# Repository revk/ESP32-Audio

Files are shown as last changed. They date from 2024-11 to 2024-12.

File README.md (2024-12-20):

## Amazon

This part if for Amazon - as this is the *manufacturers web site* and so used as proof of title and list price. It is also links to where you can buy.

|ASIN|List price|Title|
|-----|----|----|
|[B0DQH9SK8K](https://www.amazon.co.uk/dp/B0DQH9SK8K)|£35.00|Small ESP32-S3 high quality voice recorder board with stereo TDK ICS 43434 microphones, micro SD card slot, and charger circuit|

## Trademark

This is an open source project, but bear in mind you cannot sell boards bearing the Andrews & Arnold Ltd name, the A&A logo, the registered trademark AJK logo, or the GS1 allocated EANs assigned to Andrews & Arnold Ltd.

# Open†Mic

(† Open source)

This project provides software and PCB designs for working with I2S microphone and speaker, most notably a self contained battery operated audio recorder to micro SD card.

The software provides working for a number of different use cases.

The hardware is an audio recorder, but the [LED](https://github.com/revk/ESP32-LED) project also has audio hardware with microphones and speakers.

## Why use this?

There are loads of microphones and dictaphones at sensible prices, so why use this?

The main reason is flexibility - it is open source - the hardware can do a lot, and it already allows record to SD and upload by web post. It can eventually be a Bluetooth microphone, or a telephone or intercom, etc. You get to do what you like, and can make suggestions and pull requests and load your own code.

The other feature, which is becoming rarer these days, is that it is *stand alone*. No subscription. No accounts or sign up. No cloud services. Nobody training AI on your data.

## Button

Button works with short or long press (long is 3s).

* press to answer or end incoming SIP call
* press to start or stop recording
* hold (1s) to reject incoming SIP call
* hold (1s) to make a call
* hold (3s) to enter power off (will upload files at this point if option selected) - there is also an auto power off feature
* press to power back on

## Microphone

The software is designed to work with I2S audio input, and is coded and tested for two specific microphones. Others may work, but I2S has a number of options - so ask me if you need some other settings.

* [TDK T3902](https://www.lcsc.com/datasheet/lcsc_datasheet_2401291125_TDK-InvenSense-MMICT390200012_C3171752.pdf) is an I2S PDM microphone (so 16 bits per sample)
* [TDK ICS-43434](https://www.lcsc.com/datasheet/lcsc_datasheet_2312010321_TDK-InvenSense-ICS-43434_C5656610.pdf) is an I2S microphone (24 bits) with sample rates up to 51.6kHz

The software can work with one or two microphones (i.e. mono or stereo). When two microphones, they are the same type, on the same bus, with one wired as *left* and one as *right* channel. 

## Speaker

For I2S output the [MAX98357A](https://www.lcsc.com/datasheet/lcsc_datasheet_2106070436_Analog-Devices-Inc--Maxim-Integrated-MAX98357AEWL-T_C2682619.pdf) is recommended. This can be one chip working as *left*, *right*, or *left+right* channels, or as two chips on the same bus, one as *left* and one as *right*.

* `spkrate` sets the speaker rate, which (for the MAX98357A) can be 8kHz, 16kHz, 32kHz, 44.1kHz, 48kHz, 88.2kHz, or 96kHz.

## Input processing

The input from the I2S microphones can be mono or stereo, and can be 16 or 24 bits. If a PDM microphone is used it is always 16 bits. If the ICS-43434 microphone is used it is received as 24 bits which can either be passed on unprocessed, or converted to 16 bits.

* `micws` is the GPIO for the channel, if not set it is assumed to be PDM mode
* `micrate` sets the sample rate
* `micstereo` is set for stereo working
* `micright` is set for *right* channel when mono.
* `micgain` sets the gain for processing 24 bits to 16

When `micgain` is set to `0`, or when using a PDM microphone, the samples (stereo or mono) are used as received, with no processing. This means for PDM mode this is 16 bits per sample, and for ICS-43434 it is 24 bits per sample.

When `micgain` is not `0`, for ICS-43434, the 24 bit samples are processed by multiplying by `micgain/256` and clipping to 16 bits (`-32768` to `32767`). A `micgain` of `8` works well for speech.

## Output

The output via the speaker can be one of the following - normally managed via MQTT control messages or web interface, though SIP is automatic when a call arrives.

* Morse code (including prosigns in `[]`, e.g. `[INT]`) and punctuation
* DTMF
* Playing a WAV file from SD card (TODO)
* SIP (see below)

The format will depend on the source - the MAX98357A can handle 16, 24, or 32 bits per channel.

## Audio recorder



The main use of this software is as an *audio recorder*. This will record from the microphone(s) to a WAV file on the micro SD card. It allows a `button` GPIO to start/stop recording and power on/off. It allows for a separate WS2812 record status LED. The PCB design includes LiPo charging.

Options are planned:-

* Stream audio over WiFI by some means
* Stream audio over bluetooth, if ever I work out how to do that

An option exists to upload files to a web page as a `POST`, renaming the file slightly once uploaded so not uploaded twice. This is done when you hold the button to *power off`*.

An option exists to delete old files if space needed for new file.

## SIP working

The software allows settings `siphost`, `sipuser`, and `sippass`, such that the device registers with a SIP server.

Once registered it can then accept a call, and pass audio both ways over RTP, 8kHz alaw. Only one call at a time.

* The microphone is changed to mono (channel selected by `micright`) 8kHz, and either 16 bit PDM, or processed 24 bit to 16 bit using `micgain`, and then companded to alaw.
* The speaker is sent dual mono audio expanded from 8kHz alaw to 16 bits per sample.

Note that there is no echo cancellation, so a caller is likely to hear their own audio come back to them.

Once the call is complete, the audio processing reverts to previous settings.

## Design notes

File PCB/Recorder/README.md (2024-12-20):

# Audio recorder board

The Audio record board provides a shirt mount Audio board.

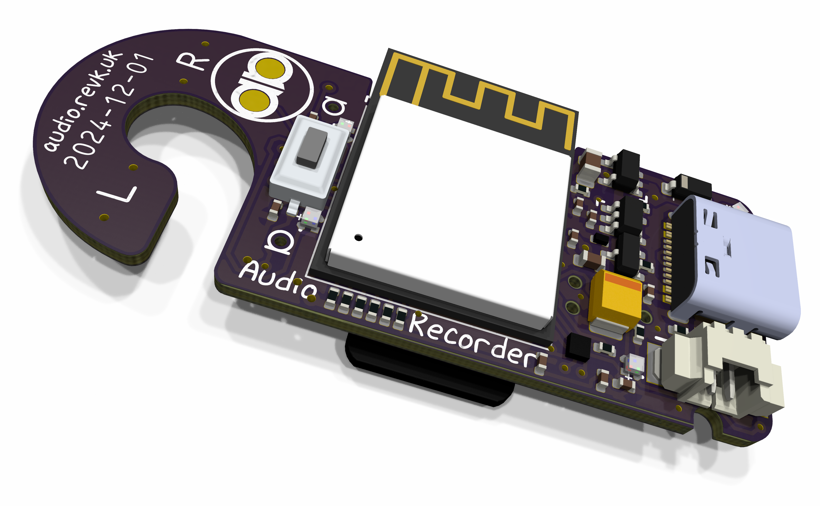
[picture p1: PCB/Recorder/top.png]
Top

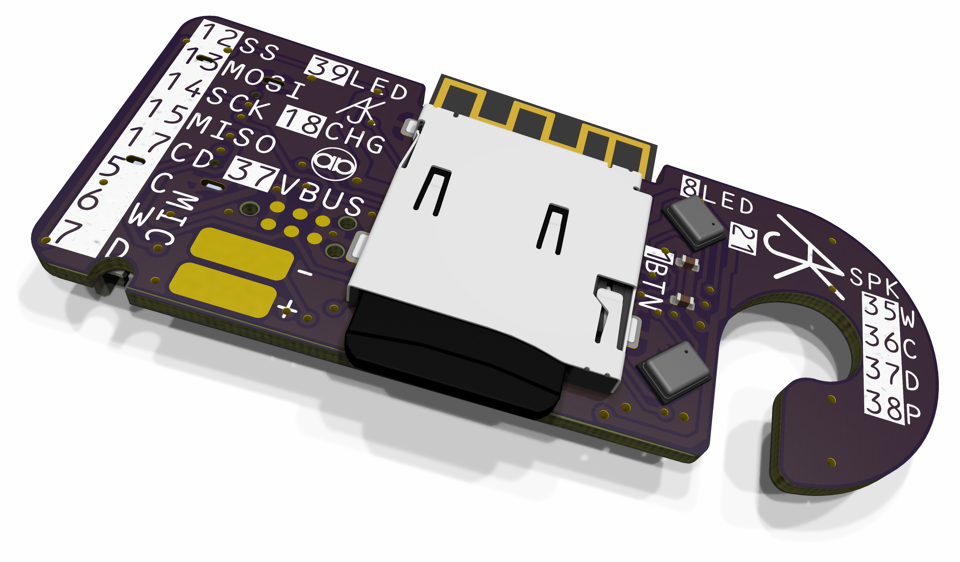
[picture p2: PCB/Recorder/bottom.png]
Bottom


Features

* LiPo battery handling and charging
* Mic, stereo TDK ICS 43434 24 bit
* SD card slot
* Button to start/stop recording, etc.

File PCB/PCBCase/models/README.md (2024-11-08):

# Models

The `models` directory contains models for the parts. These are OpenSCAD code to draw the part. This does not have to be pretty, and will often be a simple cuboid. It is used to create a cavity in the case, and any necessary holes, etc.

## Filename

For each part a file name is found for the necessary OpenSCAD code. This is done by checking a number of possible filenames until one if found.

- If there is an `LCSC Part #`, then this is checked. e.g. `C265103`
- The footprint is checked exactly, without prefix, e.g. `RevK:JST_EH_S5B-EH_1x05_P2.50mm_Horizontal` will check for `JST_EH_S5B-EH_1x05_P2.50mm_Horizontal`
- If neither of those matched, then the name of each 3D model is processed (all of them, not just the first) isong the filename without directory or suffix, e.g. `${KICAD6_3DMODEL_DIR}/Connector_JST.3dshapes/JST_EH_S5B-EH_1x05_P2.50mm_Horizontal.wrl` would check `JST_EH_S5B-EH_1x05_P2.50mm_Horizontal`.

In any case, when checking a filename (apart from the LCSC Part), any numbers in the filename are replaced with `ℕ`, e.g. for `JST_EH_S5B-EH_1x05_P2.50mm_Horizontal` the filenames checked are as follows, matching the first one found.

- `JST_EH_SℕB-EH_1x05_P2.50mm_Horizontal`
- `JST_EH_S5B-EH_ℕx05_P2.50mm_Horizontal`
- `JST_EH_S5B-EH_1xℕ_P2.50mm_Horizontal`
- `JST_EH_S5B-EH_1x05_Pℕmm_Horizontal`
- `JST_EH_S5B-EH_1x05_P2.50mm_Horizontal`

## How OpenSCAD is called

- If `N` was used in the filename, then `N` is set to the numeric value, e.g. ``JST_EH_S5B-EH_1xN_P2.50mm_Horizontal.wrl`` will have `N` et to `5`.
- For the part shape itself, `part` is set `true`.
- For the associated holes, `hole` is set `true`.
- For the associated block, `block` is set `true`.

This basically means the OpenSCAD can be called for three things...

In all cases the origin is the base of the centre of the part. The orientation is as per the 3D model.

### Orientation

When using the part number or footprint the orientation of the part matters, but when using the 3D model the exact 3D model orientation matters, so offset and rotations for the 3D model matter.

### Part

The `part` simply needs to cover the physical size/shape of the part. A function `module b(cx,cy,z,w,l,h)` is provided allowing a simple cuboid. It is possible for the part to go below the z axis, e.g. for the leads for through hole parts.

### Hole

The `hole` covers any holes in the case. This can be holes through the top of the case, e.g. for an LED to be visible. It can also cover holds in the side of the case for plugs that go in to a connector, etc.

When a hole goes through the side, the case itself is adjusted to have the cut line through the hole.

In either case, holes should be big enough for any sensible size of case.

Obviously only some parts need a hole.

### Block

The `block` is rarely used. It provides for a part of the case that must be present. It is added after the cavity is create, but before any holes. One use cases are a channel/tube around a hole for an LED in the top of the case, but this has to allow clear space on the PCB for the channel as adjacent parts won't cut in to the channel. Another use case is something like a tamper switch where a part of the case has to be present to press on the switch.

The block has to be big enough for any sensible size of case, it is truncated so it is within the case.

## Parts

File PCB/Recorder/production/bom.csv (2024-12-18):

Designator | Footprint | Quantity | Value | LCSC Part #
C1 | CP_EIA-3528-21_Kemet-B | 1 | 220uF Tant | C122649
C10, C13, C2, C4, C5, C6, C8 | C_0402 | 7 | 100nF
C11, C7 | C_0402 | 2 | 10uF 6.3V | C15525
C16 | C_0805 | 1 | 100uF | C141660
C3 | C_0603 | 1 | 22uF
C9 | C_0402 | 1 | 1uF
D1, D4, D5, D6 | SMD1010 | 4 | XL-1010RGBC-WS2812B | C5349953
D2 | DFN1006-2L | 1 | ~ | C5137770
D3 | D_SOD-123 | 1 | MBR0530
J1 | 1.25T-2PWT (Molex 532610271) | 1 | Battery | C177225
J4 | TF_PUSH | 1 | TF_PUSH | C393941
J5 | USB-C-Socket-H | 1 | USB-C-Socket-H | C709357
Q2 | SOT-23 | 1 | CJ2301 | C8547
R1, R10, R11, R12, R13, R14, R2, R3, R7, R8, R9 | R_0402 | 11 | 10K
R5, R6 | R_0402 | 2 | 5K1
SW1 | TS-1092S-B3D2-G | 1 | SW_Push
U1 | ICS43434_MEMS_Mic_Open | 1 | R | C5656610
U2 | ICS43434_MEMS_Mic_Open | 1 | L | C5656610
U3 | SOT-23-5 | 1 | TP4054 | C668215
U4 | SOT-23-5 | 1 | ME6211C33M5G-N | C82942
U6 | ESP32-S3-MINI-1 | 1 | ESP32-S3-MINI-1 | C3013941

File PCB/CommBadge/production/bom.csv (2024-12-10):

Designator | Footprint | Quantity | Value | LCSC Part #
C1 | CP_EIA-3528-21_Kemet-B | 1 | 220uF Tant | C122649
C10, C11, C12, C14, C15, C16, C17, C18, C2, C6 | C_0402 | 10 | 100nF
C13, C7, C8 | C_0402 | 3 | 10uF | C15525
C3 | C_0603 | 1 | 22uF
C4 | C_0805 | 1 | 100uF | C141660
C5 | C_0603 | 1 | 10uF 35V | C194427
C9 | C_0402 | 1 | 1uF
D1, D3 | DFN1006-2L | 2 | ~ | C5137770
D2 | D_SOD-123 | 1 | MBR0530
D4, D5, D6, D7, D8, D9 | SMD1010 | 6 | XL-1010RGBC-WS2812B | C5349953
J2 | 1.25T-2PWT (Molex 532610271) | 1 | Battery | C177225
J5 | USB-C-Socket-H | 1 | USB-C-Socket-H | C709357
LS1 | KLJ-Speaker | 1 | Speaker | C18186315
Q1 | SOT-23 | 1 | CJ2301 | C5224170
R1, R2, R3, R4 | R_0402 | 4 | 10K
R5, R6 | R_0402 | 2 | 5K1
R8 | R_0402 | 1 | 634K
SW2 | TS-1092S-B3D2-G | 1 | SW_Push
U2 | WLP-1.437mmx1.347mm-0.21mm-ball | 1 | MAX98357A
U3 | SOT-23-5 | 1 | TP4054 | C668215
U4 | SOT-23-5 | 1 | ME6211C33M5G-N | C82942
U5 | ICS43434_MEMS_Mic_Open | 1 | L | C5656610
U6 | ESP32-S3-MINI-1 | 1 | ESP32-S3-MINI-1 | C3013941
U7 | ICS43434_MEMS_Mic_Open | 1 | R | C5656610

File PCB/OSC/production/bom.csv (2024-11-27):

Designator | Footprint | Quantity | Value | LCSC Part #
C1 | CP_EIA-3528-21_Kemet-B | 1 | 220uF Tant | C122649
C10 | C_0603_ | 1 | 10uF 35V | C194427
C11 | C_0603_ | 1 | 10uF 6.3V | C1691
C12 | C_0603_ | 1 | 100nF
C15, C2 | C_0402 | 2 | 100nF
C3 | C_0603 | 1 | 22uF
C5 | C_0603 | 1 | 10uF 35V | C194427
C7, C8 | C_0402 | 2 | 10uF | C15525
C9 | C_0402 | 1 | 1uF
D1 | SMD1010 | 1 | XL-1010RGBC-WS2812B | C5349953
D2, D3, D4, D5 | DFN1006-2L | 4 | ~ | C5137770
J2 | WAGO-2060-453-998-404 | 1 | Wago | C2765056
J4 | WAGO-2060-452-998-404 | 1 | DC | C2765055
J5 | USB-C-Socket-H | 1 | USB-C-Socket-H | C709357
J6 | WAGO-2060-452-998-404 | 1 | RELAY1 | C2765055
J7 | WAGO-2060-452-998-404 | 1 | RELAY2 | C2765055
L2 | L_4x4_ | 1 | 10uH
R1 | R_0402 | 1 | 124K
R10, R7 | R_0402 | 2 | 1K
R14 | R_0402_ | 1 | 39k2
R15 | R_0402_ | 1 | 1M
R2, R3 | R_0402 | 2 | 10K
R4 | R_0402_ | 1 | 124k
R5, R6 | R_0402 | 2 | 5K1
SW1, SW3 | TS-1092S-B3D2-G | 2 | SW_Push
SW2 | Reed-59170 | 1 | SW_Reed | C315909
U1 | ICS43434_MEMS_Mic | 1 | ICS43434_MEMS_Mic | C5656610
U3, U8 | SO-4_4.4x4.3mm_P2.54mm | 2 | Relay | C2691608
U4 | SOT-23 | 1 | 78L05 | C22392284
U6 | ESP32-S3-MINI-1 | 1 | ESP32-S3-MINI-1 | C3013941
U7 | SOT-23-6-MD8942 | 1 | MD8942 | C2684786
U9 | VEML6040 | 1 | VEML6040 | C78465

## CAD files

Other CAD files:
PCB/PCBCase/models/Crystal_SMD_Abracon_ABM8G-4Pin_3.2x2.5mm.scad
PCB/PCBCase/models/PinHeader_1x0_P1.27mm_Vertical.scad
PCB/PCBCase/models/PinHeader_1x0_P2.54mm_Horizontal.scad
PCB/PCBCase/models/PinHeader_1x0_P2.54mm_Vertical.scad
PCB/PCBCase/case.scad
PCB/PCBCase/models/22057025.scad
PCB/PCBCase/models/22057035.scad
PCB/PCBCase/models/22057045.scad
PCB/PCBCase/models/22057055.scad
PCB/PCBCase/models/22057065.scad
PCB/PCBCase/models/22057075.scad
PCB/PCBCase/models/22057085.scad
PCB/PCBCase/models/22057095.scad
PCB/PCBCase/models/22057105.scad
PCB/PCBCase/models/653612.scad
PCB/PCBCase/models/D_0603_1608Metric.scad
PCB/PCBCase/models/D_0805_2012Metric.scad
PCB/PCBCase/models/D_1206_3216Metric.scad
PCB/PCBCase/models/ESE58L61B.scad
PCB/PCBCase/models/ESP32-WROOM-32.scad
PCB/PCBCase/models/HSOP-8-1EP_3.9x4.9mm_P1.27mm_EP2.41x3.1mm.scad
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

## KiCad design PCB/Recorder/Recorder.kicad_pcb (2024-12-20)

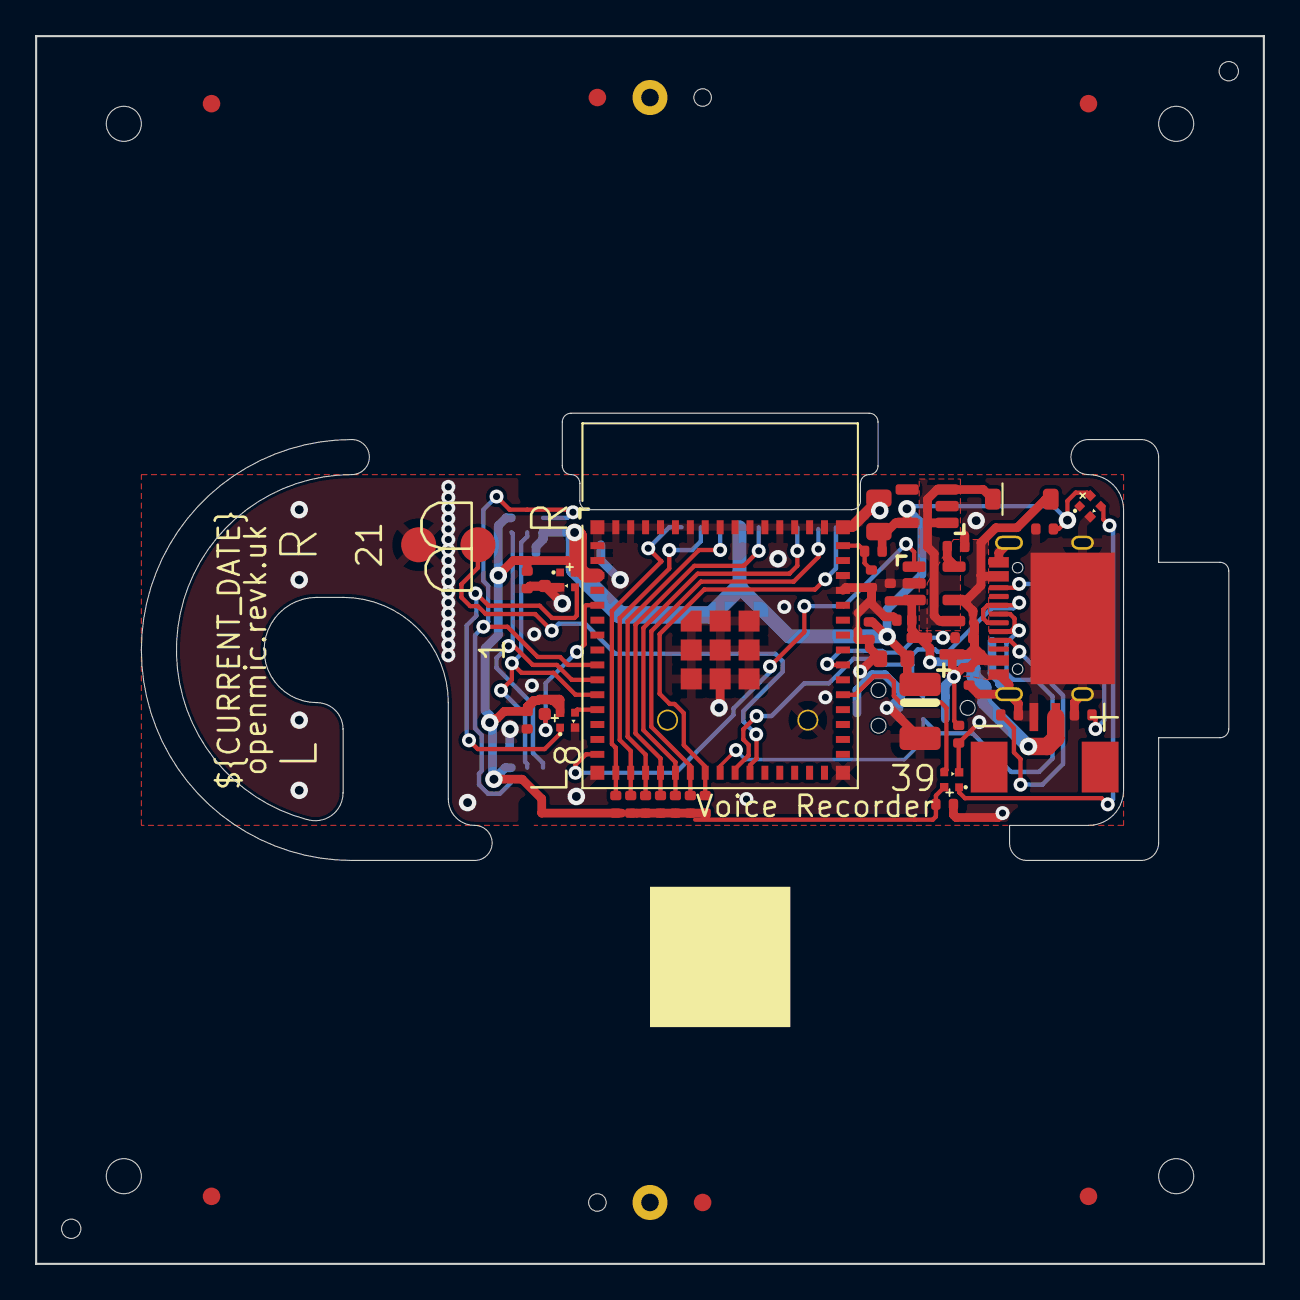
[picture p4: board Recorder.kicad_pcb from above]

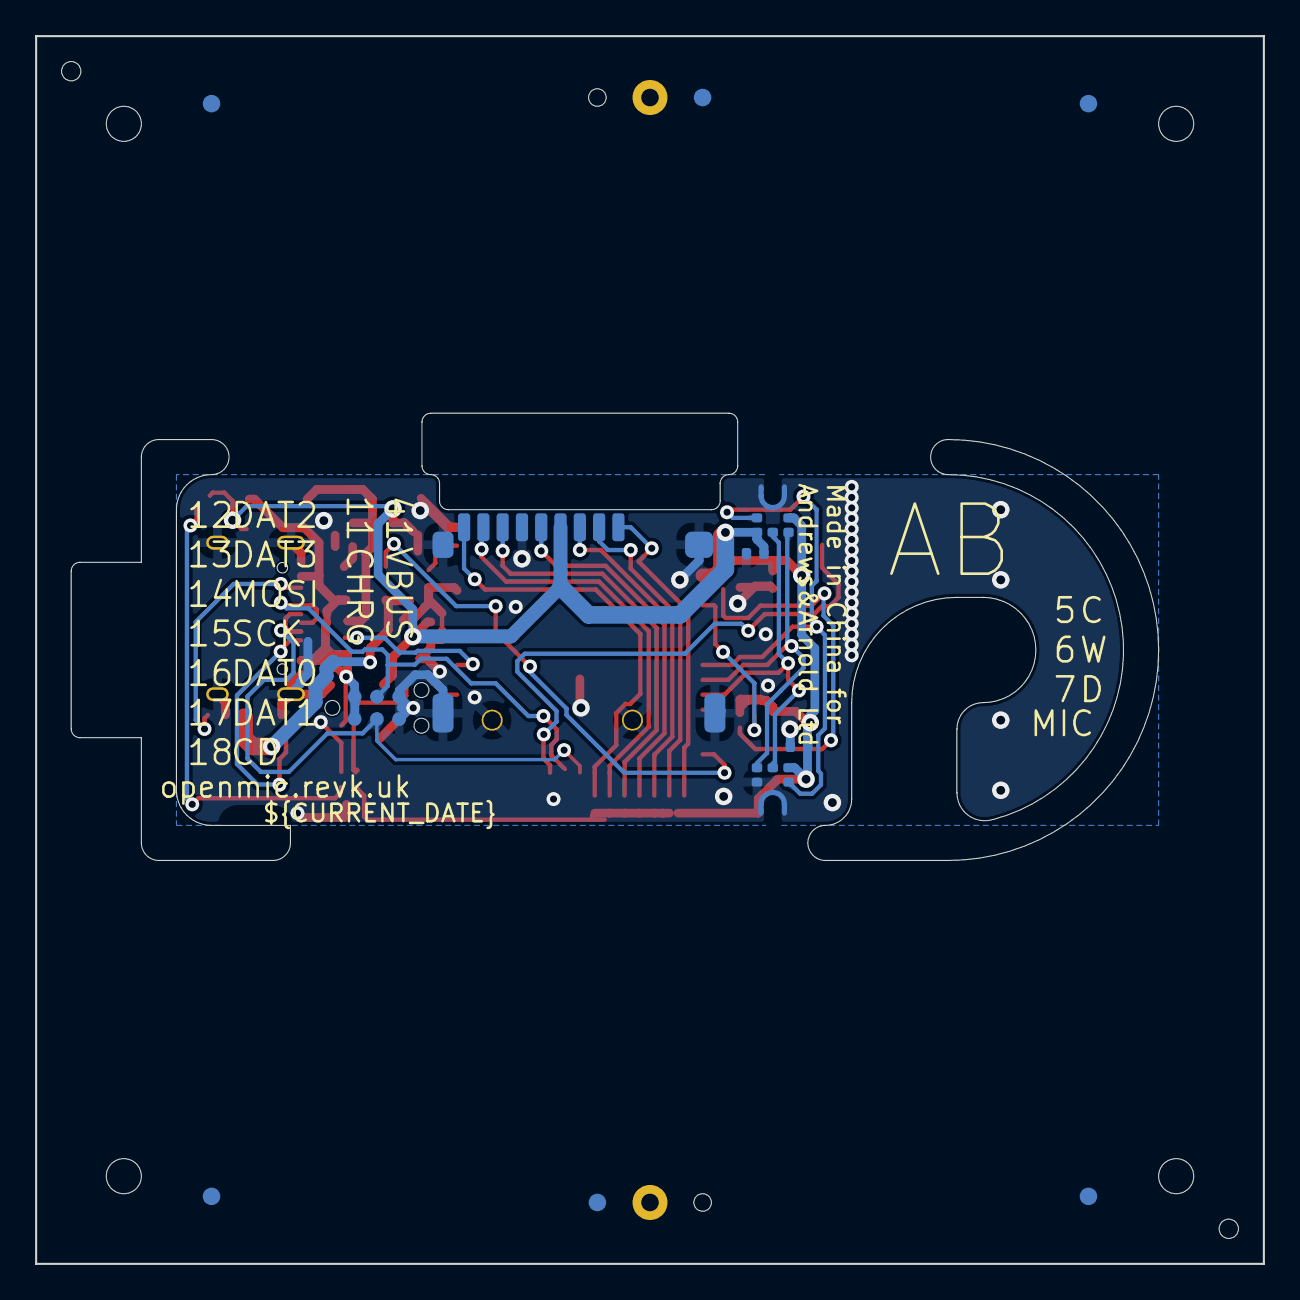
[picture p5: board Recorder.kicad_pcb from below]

Board: 2 copper layers, 70.0 x 70.0 mm, 47 parts (7 on the bottom side), 29 nets.

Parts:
C1: 220uF Tant; CP_EIA-3528-21_Kemet-B
C2, C4, C5, C6, C8, C10, C13: 100nF; C_0402
C3: 22uF; C_0603
C7, C11: 10uF 6.3V; C_0402
C9: 1uF; C_0402
C16: 100uF; C_0805
D1, D4, D5, D6: XL-1010RGBC-WS2812B; SMD1010
D2: DFN1006-2L
D3: MBR0530; D_SOD-123
J1: Battery; 1.25T-2PWT (Molex 532610271)
J2: Reset; AA-Pad
J3: TC2030-USB-NL-DS; Tag-Connect_TC2030-IDC-NL_2x03_P1.27mm_Vertical
J4: TF_PUSH
J5: USB-C-Socket-H
PCB1: 70x70; PCB7070
Q2: CJ2301; SOT-23
R1, R2, R3, R7, R8, R9, R10, R11, R12, R13, R14: 10K; R_0402
R5, R6: 5K1; R_0402
SW1: SW_Push; TS-1092S-B3D2-G
U1: R; ICS43434_MEMS_Mic_Open
U2: L; ICS43434_MEMS_Mic_Open
U3: TP4054; SOT-23-5
U4: ME6211C33M5G-N; SOT-23-5
U6: ESP32-S3-MINI-1
V1, V2: VCUT70N

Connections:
+3V3: C1.1, C2.1, C3.1, C4.1, C5.1, C6.1, C8.2, C10.1, C13.2, C16.1, D1.2 (+), D4.2 (+), D5.2 (+), D6.2 (+), J4.4 (VDD), R2.1, R3.1, R9.1, R10.1, R11.1, R12.1, R13.1, R14.1, U1.2 (LR), U1.5 (VDD), U2.5 (VDD), U4.5 (OUT), U6.3 (3V3)
BLINK: D1.4 (I), U6.35 (GPIO39)
BUTTON: SW1.2, U6.5 (GPIO1)
CHARGING: U3.1 (STAT), U6.15 (GPIO11)
D+: J3.4 (D+), J5.A6 (D+), J5.B6 (D+), U6.24 (GPIO20)
D-: J3.3 (D-), J5.A7 (D-), J5.B7 (D-), U6.23 (GPIO19)
GND: C1.2, C2.2, C3.2, C4.2, C5.2, C6.2, C7.2, C8.1, C9.2, C10.2, C11.2, C13.1, C16.2, D1.3 (-), D2.1, D4.3 (-), D5.3 (-), D6.3 (-), J1.2, J2.1, J3.5 (GND), J3.6 (GND), J4.6 (VSS), J4.S (SHIELD), J5.A1 (GND), J5.A12 (GND), J5.B1 (GND), J5.B12 (GND), J5.S1 (SHIELD), R1.1, R5.2, R6.1, R8.2, SW1.1, U1.3 (GND), U2.2 (LR), U2.3 (GND), U3.2 (VSS), U4.2 (GND), U6.1 (GND), U6.2 (GND), U6.42 (GND), U6.43 (GND), U6.46 (GND), U6.47 (GND), U6.48 (GND), U6.49 (GND), U6.50 (GND), U6.51 (GND), U6.52 (GND), U6.53 (GND), U6.54 (GND), U6.55 (GND), U6.56 (GND), U6.57 (GND), U6.58 (GND), U6.59 (GND), U6.60 (GND), U6.61 (GND), U6.62 (GND), U6.63 (GND), U6.64 (GND), U6.65 (GND)
LEDMIC: D5.4 (I), U6.12 (GPIO8)
unnamed: D1.1 (O), D6.4 (I)
unnamed: D3.1 (K), Q2.2 (S), U4.1 (IN), U4.3 (EN)
unnamed: D4.4 (I), D5.1 (O)
unnamed: J2.2, U6.25 (GPIO21)
unnamed: J5.A5 (CC1), R5.1
unnamed: J5.B5 (CC2), R6.2
unnamed: R1.2, U3.5 (PROG)
unnamed: C9.1, R2.2, U6.45 (EN)
unnamed: R7.1, U6.37 (GPIO41)
SCK: U1.4 (SCK), U2.4 (SCK), U6.9 (GPIO5)
SD: U1.6 (SD), U2.6 (SD), U6.11 (GPIO7)
SDCD: J4.9 (CD), R3.2, U6.22 (GPIO18)
SDCLK: J4.5 (CLK), R11.2, U6.19 (GPIO15)
SDCMD: J4.3 (CMD), R12.2, U6.18 (GPIO14)
SDDAT0: J4.7 (DAT0), R10.2, U6.20 (GPIO16)
SDDAT1: J4.8 (DAT1), R9.2, U6.21 (GPIO17)
SDDAT2: J4.1 (DAT2), R14.2, U6.16 (GPIO12)
SDDAT3: J4.2 (DAT3/CD), R13.2, U6.17 (GPIO13)
VBAT: C7.1, D2.2, J1.1, Q2.3 (D), U3.3 (VBAT)
VBUS: C11.1, D3.2 (A), J3.1 (VBUS), J3.2 (VBUS), J5.A4 (VBUS), J5.A9 (VBUS), J5.B4 (VBUS), J5.B9 (VBUS), Q2.1 (G), R7.2, R8.1, U3.4 (VDD)
WS: U1.1 (WS), U2.1 (WS), U6.10 (GPIO6)

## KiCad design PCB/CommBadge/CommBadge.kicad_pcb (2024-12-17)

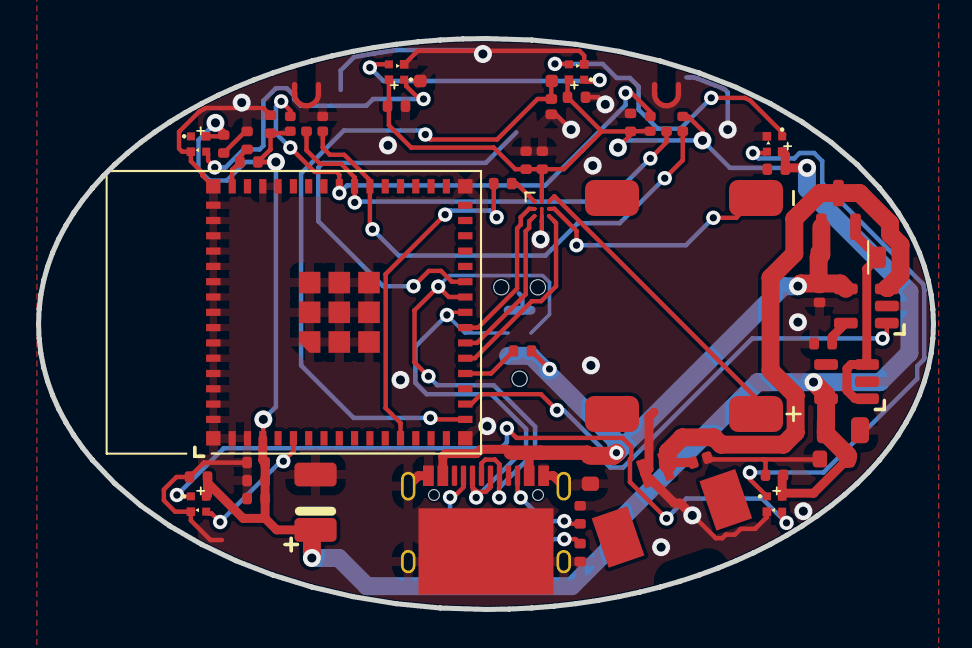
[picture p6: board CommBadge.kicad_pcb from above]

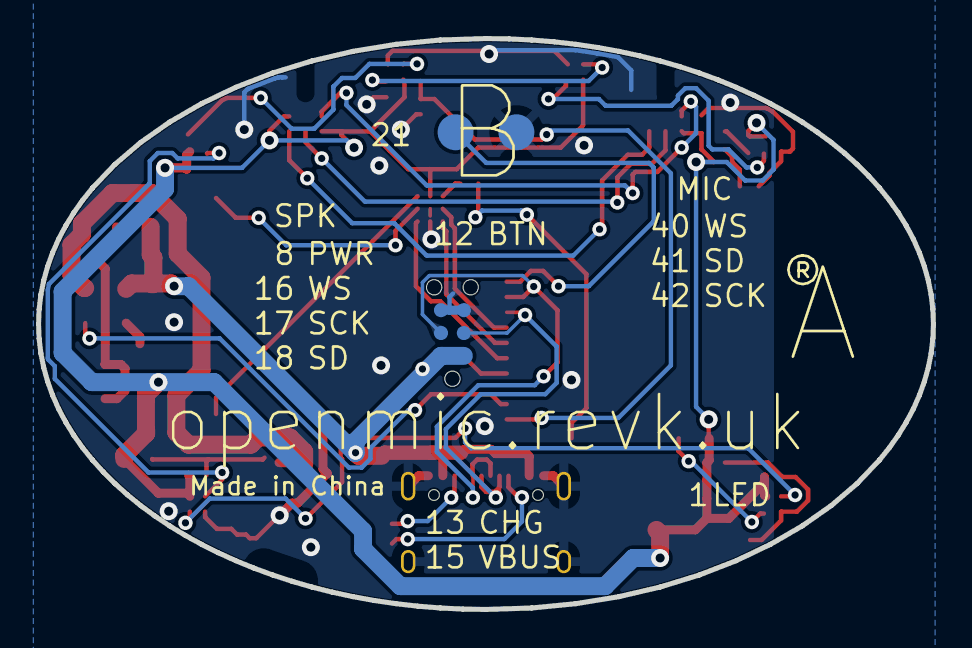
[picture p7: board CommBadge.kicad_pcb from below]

Board: 2 copper layers, 49.7 x 31.7 mm, 47 parts (2 on the bottom side), 31 nets.

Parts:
C1: 220uF Tant; CP_EIA-3528-21_Kemet-B
C2, C6, C10, C11, C12, C14, C15, C16, C17, C18: 100nF; C_0402
C3: 22uF; C_0603
C4: 100uF; C_0805
C5: 10uF 35V; C_0603
C7, C8, C13: 10uF; C_0402
C9: 1uF; C_0402
D1, D3: DFN1006-2L
D2: MBR0530; D_SOD-123
D4, D5, D6, D7, D8, D9: XL-1010RGBC-WS2812B; SMD1010
J1: Reset; AA-Pad
J2: Battery; 1.25T-2PWT (Molex 532610271)
J3: TC2030-USB-NL-DS; Tag-Connect_TC2030-IDC-NL_2x03_P1.27mm_Vertical
J5: USB-C-Socket-H
LS1: Speaker; KLJ-Speaker
Q1: CJ2301; SOT-23
R1, R2, R3, R4: 10K; R_0402
R5, R6: 5K1; R_0402
R8: 634K; R_0402
SW2: SW_Push; TS-1092S-B3D2-G
U2: MAX98357A; WLP-1.437mmx1.347mm-0.21mm-ball
U3: TP4054; SOT-23-5
U4: ME6211C33M5G-N; SOT-23-5
U5: L; ICS43434_MEMS_Mic_Open
U6: ESP32-S3-MINI-1
U7: R; ICS43434_MEMS_Mic_Open

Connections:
+3V3: C1.1, C2.1, C3.1, C4.1, C6.2, C7.1, C8.1, C10.2, C11.1, C12.1, C13.1, C14.1, C15.1, C16.1, C17.1, C18.1, D4.2 (+), D5.2 (+), D6.2 (+), D7.2 (+), D8.2 (+), D9.2 (+), R2.1, U2.A2 (VDD), U4.5 (OUT), U5.5 (VDD), U6.3 (3V3), U7.2 (LR), U7.5 (VDD)
CHARGING: U3.1 (STAT), U6.17 (GPIO13)
D+: J3.4 (D+), J5.A6 (D+), J5.B6 (D+), U6.24 (GPIO20)
D-: J3.3 (D-), J5.A7 (D-), J5.B7 (D-), U6.23 (GPIO19)
GND: C1.2, C2.2, C3.2, C4.2, C5.2, C6.1, C7.2, C8.2, C9.2, C10.1, C11.2, C12.2, C13.2, C14.2, C15.2, C16.2, C17.2, C18.2, D1.1, D3.1, D4.3 (-), D5.3 (-), D6.3 (-), D7.3 (-), D8.3 (-), D9.3 (-), J1.1, J2.2, J3.5 (GND), J3.6 (GND), J5.A1 (GND), J5.A12 (GND), J5.B1 (GND), J5.B12 (GND), J5.S1 (SHIELD), R1.1, R3.2, R5.2, R6.1, SW2.1, U2.B2 (GAIN_SLOT), U2.C2 (GND), U3.2 (VSS), U4.2 (GND), U5.2 (LR), U5.3 (GND), U6.1 (GND), U6.2 (GND), U6.42 (GND), U6.43 (GND), U6.46 (GND), U6.47 (GND), U6.48 (GND), U6.49 (GND), U6.50 (GND), U6.51 (GND), U6.52 (GND), U6.53 (GND), U6.54 (GND), U6.55 (GND), U6.56 (GND), U6.57 (GND), U6.58 (GND), U6.59 (GND), U6.60 (GND), U6.61 (GND), U6.62 (GND), U6.63 (GND), U6.64 (GND), U6.65 (GND), U7.3 (GND)
MICSCK: U5.4 (SCK), U6.38 (GPIO42), U7.4 (SCK)
MICSD: U5.6 (SD), U6.37 (GPIO41), U7.6 (SD)
MICWS: U5.1 (WS), U6.36 (GPIO40), U7.1 (WS)
unnamed: D2.1 (K), Q1.2 (S), U4.1 (IN), U4.3 (EN)
unnamed: D4.4 (I), D9.1 (O)
unnamed: D4.1 (O), D5.4 (I)
unnamed: D5.1 (O), D8.4 (I)
unnamed: D6.4 (I), D8.1 (O)
unnamed: D6.1 (O), D7.4 (I)
unnamed: J1.2, U6.25 (GPIO21)
unnamed: J5.A5 (CC1), R5.1
unnamed: J5.B5 (CC2), R6.2
unnamed: LS1.2, U2.B3 (OUTN)
unnamed: LS1.1, U2.A3 (OUTP)
unnamed: R8.1, U2.A1 (~SD_MODE)
unnamed: R1.2, U3.5 (PROG)
unnamed: C9.1, R2.2, U6.45 (EN)
unnamed: R4.2, U6.19 (GPIO15)
PUSH: D3.2, SW2.2, U6.16 (GPIO12)
RGB: D9.4 (I), U6.5 (GPIO1)
SKPPWR: R8.2, U6.12 (GPIO8)
SKPSCK: U2.C1 (BCLK), U6.21 (GPIO17)
SKPSD: U2.B1 (DIN), U6.22 (GPIO18)
SKPWS: U2.C3 (LRCLK), U6.20 (GPIO16)
VBAT: D1.2, J2.1, Q1.3 (D), U3.3 (VBAT)
VBUS: C5.1, D2.2 (A), J3.1 (VBUS), J3.2 (VBUS), J5.A4 (VBUS), J5.A9 (VBUS), J5.B4 (VBUS), J5.B9 (VBUS), Q1.1 (G), R3.1, R4.1, U3.4 (VDD)

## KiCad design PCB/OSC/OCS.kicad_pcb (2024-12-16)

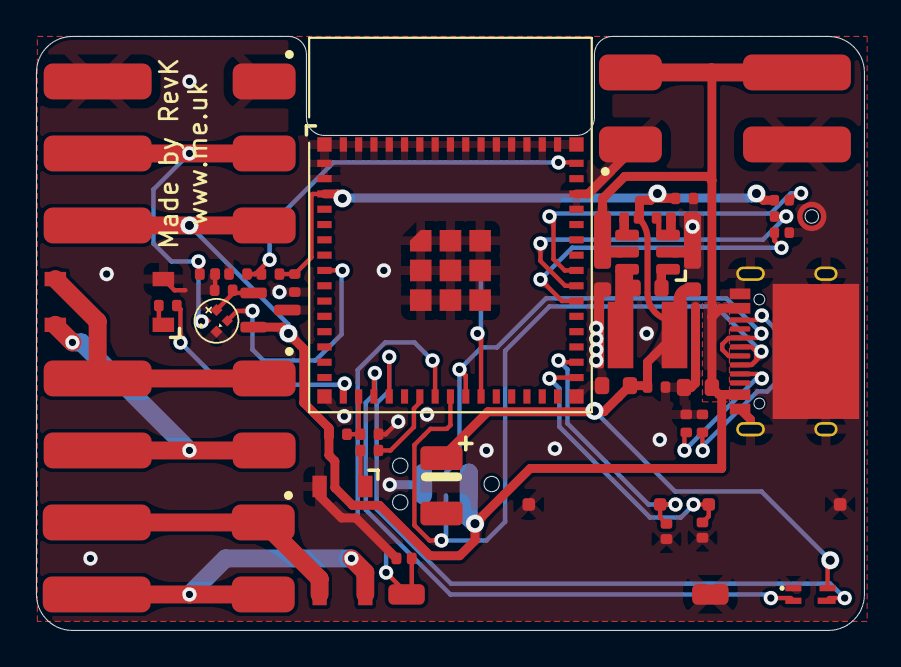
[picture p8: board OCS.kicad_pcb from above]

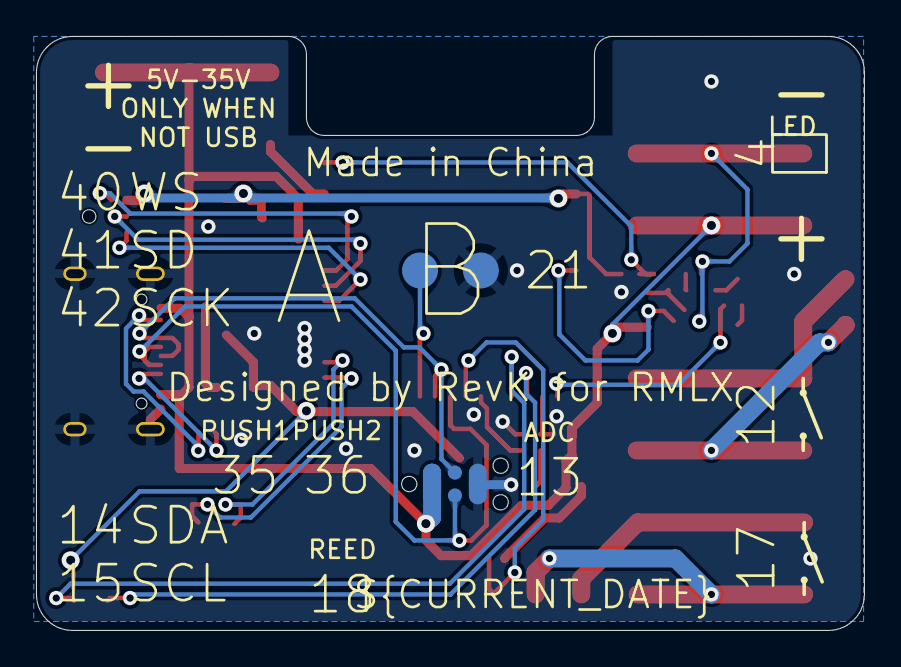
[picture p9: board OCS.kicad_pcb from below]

Board: 2 copper layers, 46.0 x 33.0 mm, 44 parts (2 on the bottom side), 29 nets.

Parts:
C1: 220uF Tant; CP_EIA-3528-21_Kemet-B
C2, C15: 100nF; C_0402
C3: 22uF; C_0603
C5: 10uF 35V; C_0603
C7, C8: 10uF; C_0402
C9: 1uF; C_0402
C10: 10uF 35V; C_0603_
C11: 10uF 6.3V; C_0603_
C12: 100nF; C_0603_
D1: XL-1010RGBC-WS2812B; SMD1010
D2, D3, D4, D5: DFN1006-2L
J1: Reset; AA-Pad
J2: Wago; WAGO-2060-453-998-404
J3: TC2030-USB-NL-DS; Tag-Connect_TC2030-IDC-NL_2x03_P1.27mm_Vertical
J4: DC; WAGO-2060-452-998-404
J5: USB-C-Socket-H
J6: RELAY1; WAGO-2060-452-998-404
J7: RELAY2; WAGO-2060-452-998-404
L2: 10uH; L_4x4_
R1: 124K; R_0402
R2, R3: 10K; R_0402
R4: 124k; R_0402_
R5, R6: 5K1; R_0402
R7, R10: 1K; R_0402
R14: 39k2; R_0402_
R15: 1M; R_0402_
SW1, SW3: SW_Push; TS-1092S-B3D2-G
SW2: SW_Reed; Reed-59170
U1: ICS43434_MEMS_Mic
U3, U8: Relay; SO-4_4.4x4.3mm_P2.54mm
U4: 78L05; SOT-23
U6: ESP32-S3-MINI-1
U7: MD8942; SOT-23-6-MD8942
U9: VEML6040

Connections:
+3V3: C1.1, C2.1, C3.1, C7.1, C8.1, R2.1, U1.5 (VDD), U6.3 (3V3), U7.8 (VOUT), U9.4 (VDD)
ADC: R1.2, R3.1, U6.17 (GPIO13)
D+: J3.4 (D+), J5.A6 (D+), J5.B6 (D+), U6.24 (GPIO20)
D-: J3.3 (D-), J5.A7 (D-), J5.B7 (D-), U6.23 (GPIO19)
DC: C5.1, J2.3, J3.1 (VBUS), J3.2 (VBUS), J4.2, J5.A4 (VBUS), J5.A9 (VBUS), J5.B4 (VBUS), J5.B9 (VBUS), R1.1, U4.2 (IN), U7.5 (VIN)
GND: C1.2, C2.2, C3.2, C5.2, C7.2, C8.2, C9.2, C15.2, D1.3 (-), D2.1, D3.1, D4.1, D5.1, J1.1, J2.1, J3.5 (GND), J3.6 (GND), J4.1, J5.A1 (GND), J5.A12 (GND), J5.B1 (GND), J5.B12 (GND), J5.S1 (SHIELD), R3.2, R5.2, R6.1, SW1.1, SW2.2, SW3.1, U1.2 (LR), U1.3 (GND), U3.2, U4.3 (GND), U6.1 (GND), U6.2 (GND), U6.42 (GND), U6.43 (GND), U6.46 (GND), U6.47 (GND), U6.48 (GND), U6.49 (GND), U6.50 (GND), U6.51 (GND), U6.52 (GND), U6.53 (GND), U6.54 (GND), U6.55 (GND), U6.56 (GND), U6.57 (GND), U6.58 (GND), U6.59 (GND), U6.60 (GND), U6.61 (GND), U6.62 (GND), U6.63 (GND), U6.64 (GND), U6.65 (GND), U7.2 (GND), U7.7 (GND), U8.2, U9.1 (GND)
LED1: D1.4 (I), U6.8 (GPIO4)
LED2: D1.1 (O), D2.2, J2.2
MICSCK: U1.4 (SCK), U6.38 (GPIO42)
MICSD: U1.6 (SD), U6.37 (GPIO41)
MICWS: U1.1 (WS), U6.36 (GPIO40)
unnamed: C15.1, D1.2 (+), U4.1 (OUT)
unnamed: J1.2, U6.25 (GPIO21)
unnamed: J5.A5 (CC1), R5.1
unnamed: J5.B5 (CC2), R6.2
unnamed: J6.1, U3.3
unnamed: J6.2, U3.4
unnamed: J7.1, U8.3
unnamed: J7.2, U8.4
unnamed: R7.1, U3.1
unnamed: R10.1, U8.1
unnamed: C9.1, R2.2, U6.45 (EN)
PUSH1: D3.2, SW3.2, U6.31 (GPIO35)
PUSH2: D4.2, SW1.2, U6.32 (GPIO36)
REED: D5.2, SW2.1, U6.22 (GPIO18)
RELAY1: R7.2, U6.16 (GPIO12)
RELAY2: R10.2, U6.21 (GPIO17)
SCL: U6.19 (GPIO15), U9.3 (SCL)
SDA: U6.18 (GPIO14), U9.2 (SDA)

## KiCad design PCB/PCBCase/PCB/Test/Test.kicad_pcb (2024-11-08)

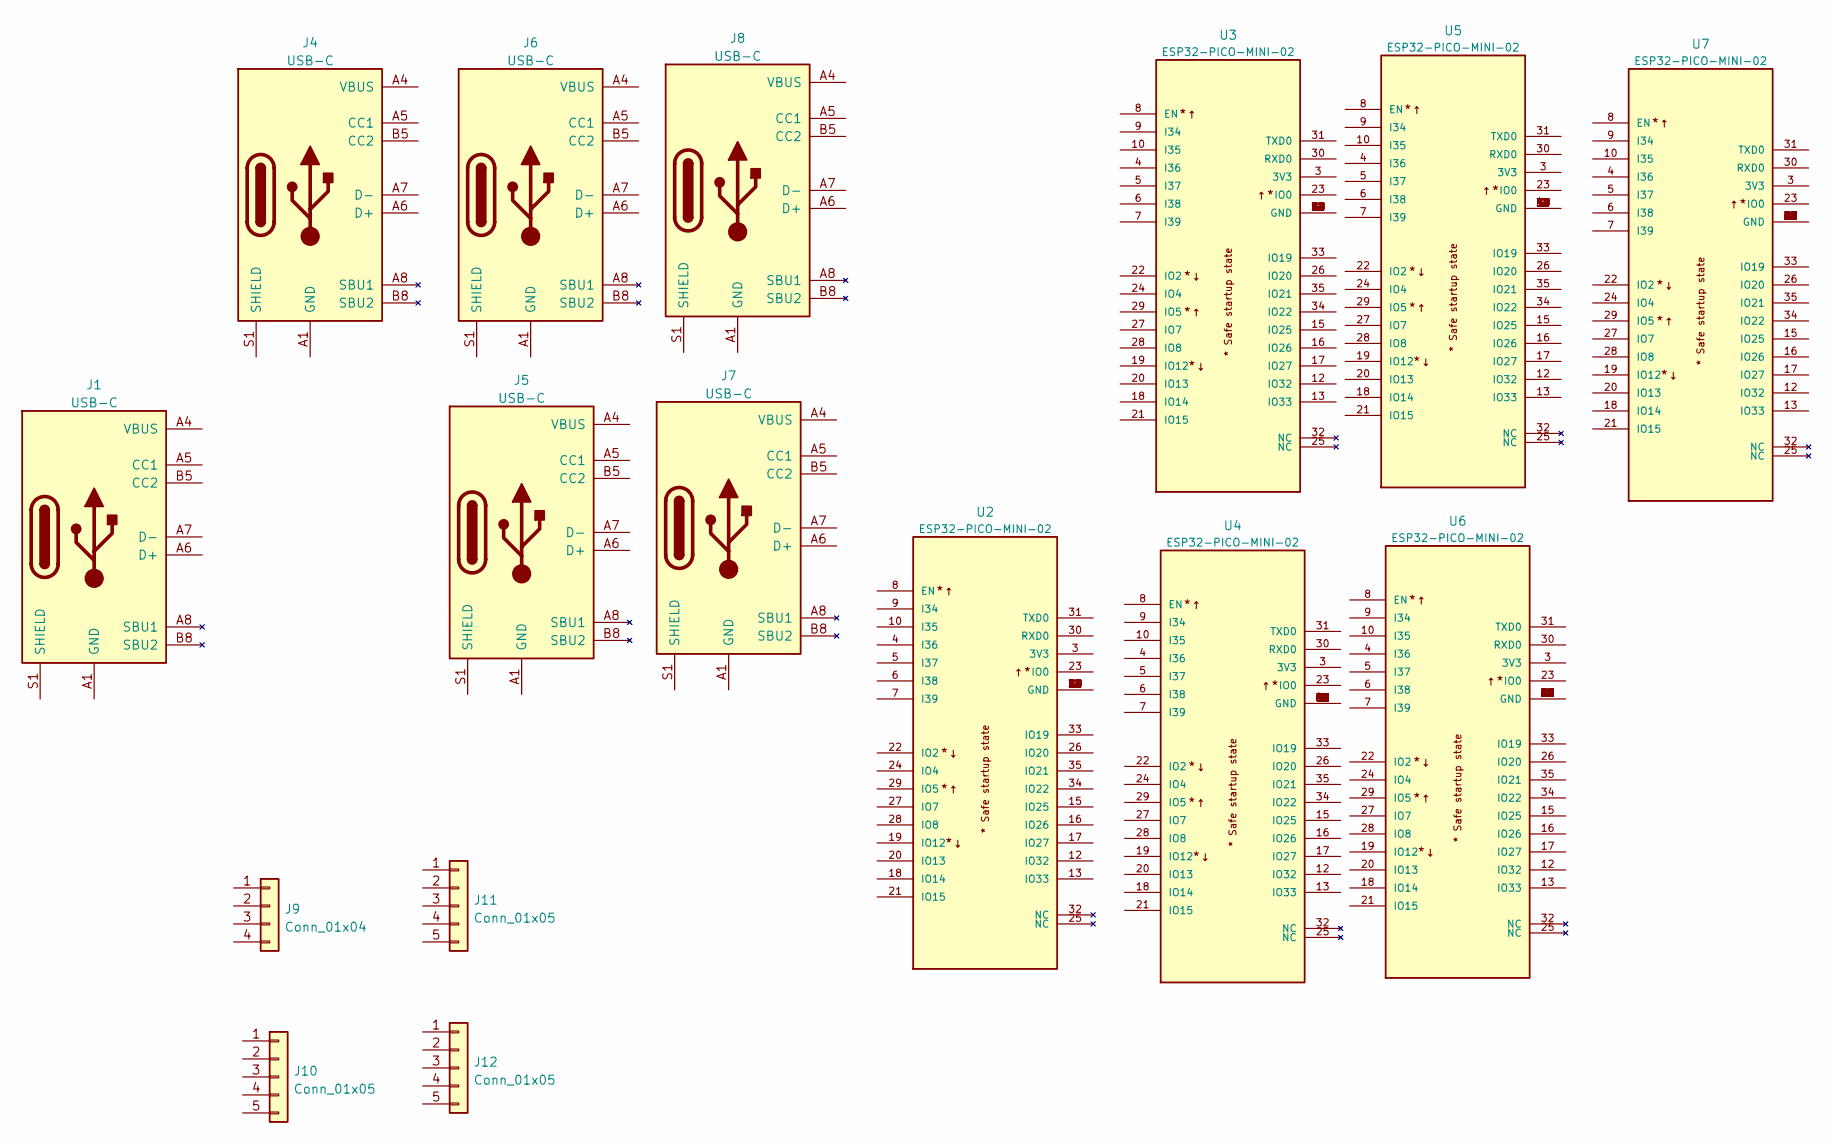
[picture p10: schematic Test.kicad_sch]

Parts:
J1, J4, J5, J6, J7, J8: USB-C; USC16-TR-Round
J9: Conn_01x04; JLC-PinHeader_1x04_P2.54mm_Right
J10: Conn_01x05; PTSM-HH-5-RA-P
J11: Conn_01x05; PTSM-HH-5-RA
J12: Conn_01x05; PTSM-HH-5-RA-P-SMD
U2, U3, U4, U5, U6, U7: ESP32-PICO-MINI-02; PARTREV v1.0

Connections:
unnamed: J1.A1 (GND), J1.A12 (GND), J1.B1 (GND), J1.B12 (GND)
unnamed: J1.A4 (VBUS), J1.A9 (VBUS), J1.B4 (VBUS), J1.B9 (VBUS)
unnamed: J1.A6 (D+), J1.B6 (D+)
unnamed: J1.A7 (D-), J1.B7 (D-)
unnamed: J4.A1 (GND), J4.A12 (GND), J4.B1 (GND), J4.B12 (GND)
unnamed: J4.A4 (VBUS), J4.A9 (VBUS), J4.B4 (VBUS), J4.B9 (VBUS)
unnamed: J4.A6 (D+), J4.B6 (D+)
unnamed: J4.A7 (D-), J4.B7 (D-)
unnamed: J5.A1 (GND), J5.A12 (GND), J5.B1 (GND), J5.B12 (GND)
unnamed: J5.A4 (VBUS), J5.A9 (VBUS), J5.B4 (VBUS), J5.B9 (VBUS)
unnamed: J5.A6 (D+), J5.B6 (D+)
unnamed: J5.A7 (D-), J5.B7 (D-)
unnamed: J6.A1 (GND), J6.A12 (GND), J6.B1 (GND), J6.B12 (GND)
unnamed: J6.A4 (VBUS), J6.A9 (VBUS), J6.B4 (VBUS), J6.B9 (VBUS)
unnamed: J6.A6 (D+), J6.B6 (D+)
unnamed: J6.A7 (D-), J6.B7 (D-)
unnamed: J7.A1 (GND), J7.A12 (GND), J7.B1 (GND), J7.B12 (GND)
unnamed: J7.A4 (VBUS), J7.A9 (VBUS), J7.B4 (VBUS), J7.B9 (VBUS)
unnamed: J7.A6 (D+), J7.B6 (D+)
unnamed: J7.A7 (D-), J7.B7 (D-)
unnamed: J8.A1 (GND), J8.A12 (GND), J8.B1 (GND), J8.B12 (GND)
unnamed: J8.A4 (VBUS), J8.A9 (VBUS), J8.B4 (VBUS), J8.B9 (VBUS)
unnamed: J8.A6 (D+), J8.B6 (D+)
unnamed: J8.A7 (D-), J8.B7 (D-)
unnamed: U2.1 (GND), U2.2 (GND), U2.11 (GND), U2.14 (GND), U2.36 (GND), U2.37 (GND), U2.38 (GND), U2.39 (GND), U2.40 (GND), U2.41 (GND), U2.42 (GND), U2.43 (GND), U2.44 (GND), U2.45 (GND), U2.46 (GND), U2.47 (GND), U2.48 (GND), U2.49 (GND), U2.50 (GND), U2.51 (GND), U2.52 (GND), U2.53 (GND)
unnamed: U3.1 (GND), U3.2 (GND), U3.11 (GND), U3.14 (GND), U3.36 (GND), U3.37 (GND), U3.38 (GND), U3.39 (GND), U3.40 (GND), U3.41 (GND), U3.42 (GND), U3.43 (GND), U3.44 (GND), U3.45 (GND), U3.46 (GND), U3.47 (GND), U3.48 (GND), U3.49 (GND), U3.50 (GND), U3.51 (GND), U3.52 (GND), U3.53 (GND)
unnamed: U4.1 (GND), U4.2 (GND), U4.11 (GND), U4.14 (GND), U4.36 (GND), U4.37 (GND), U4.38 (GND), U4.39 (GND), U4.40 (GND), U4.41 (GND), U4.42 (GND), U4.43 (GND), U4.44 (GND), U4.45 (GND), U4.46 (GND), U4.47 (GND), U4.48 (GND), U4.49 (GND), U4.50 (GND), U4.51 (GND), U4.52 (GND), U4.53 (GND)
unnamed: U5.1 (GND), U5.2 (GND), U5.11 (GND), U5.14 (GND), U5.36 (GND), U5.37 (GND), U5.38 (GND), U5.39 (GND), U5.40 (GND), U5.41 (GND), U5.42 (GND), U5.43 (GND), U5.44 (GND), U5.45 (GND), U5.46 (GND), U5.47 (GND), U5.48 (GND), U5.49 (GND), U5.50 (GND), U5.51 (GND), U5.52 (GND), U5.53 (GND)
unnamed: U6.1 (GND), U6.2 (GND), U6.11 (GND), U6.14 (GND), U6.36 (GND), U6.37 (GND), U6.38 (GND), U6.39 (GND), U6.40 (GND), U6.41 (GND), U6.42 (GND), U6.43 (GND), U6.44 (GND), U6.45 (GND), U6.46 (GND), U6.47 (GND), U6.48 (GND), U6.49 (GND), U6.50 (GND), U6.51 (GND), U6.52 (GND), U6.53 (GND)
unnamed: U7.1 (GND), U7.2 (GND), U7.11 (GND), U7.14 (GND), U7.36 (GND), U7.37 (GND), U7.38 (GND), U7.39 (GND), U7.40 (GND), U7.41 (GND), U7.42 (GND), U7.43 (GND), U7.44 (GND), U7.45 (GND), U7.46 (GND), U7.47 (GND), U7.48 (GND), U7.49 (GND), U7.50 (GND), U7.51 (GND), U7.52 (GND), U7.53 (GND)

Board: 2 copper layers, 16 parts (6 on the bottom side), 30 nets, no tracks yet.

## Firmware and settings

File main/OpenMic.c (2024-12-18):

/* OpenMic app */
/* Copyright ©2024 Adrian Kennard, Andrews & Arnold Ltd.See LICENCE file for details .GPL 3.0 */

static const char TAG[] = "OpenMic";

#include "revk.h"
#include "esp_sleep.h"
#include "esp_task_wdt.h"
#include <netdb.h>
#include <driver/gpio.h>
#include <driver/uart.h>
#include <driver/i2c.h>
#include <driver/i2s_std.h>
#include <driver/i2s_pdm.h>
#include <driver/rtc_io.h>
#include <driver/rmt_rx.h>
#include <driver/sdmmc_host.h>
#include "esp_http_client.h"
#include <esp_http_server.h>
#include "esp_crt_bundle.h"
#include "fft.h"
#include "math.h"
#include "esp_vfs_fat.h"
#include <sys/dirent.h>
#include <sip.h>
#include "halib.h"

typedef int16_t audio_t;
#define	audio_max	32767

struct
{
   char c;
   const char *m;
} morse[] = {
   {'A', ".-"},
   {'B', "-..."},
   {'C', "-.-."},
   {'D', "-.."},
   {'E', "."},
   {'F', "..-."},
   {'G', "--."},
   {'H', "...."},
   {'I', ".."},
   {'J', ".---"},
   {'K', "-.-"},
   {'L', ".-.."},
   {'M', "--"},
   {'N', "-."},
   {'O', "---"},
   {'P', ".--."},
   {'Q', "--.-"},
   {'R', ".-."},
   {'S', "..."},
   {'T', "-"},
   {'U', "..-"},
   {'V', "...-"},
   {'W', ".--"},
   {'X', "-..-"},
   {'Y', "-.--"},
   {'Z', "--.-"},
   {'1', ".----"},
   {'2', "..---"},
   {'3', "...--"},
   {'4', "....-"},
   {'5', "....."},
   {'6', "-...."},
   {'7', "--..."},
   {'8', "---.."},
   {'9', "----."},
   {'0', "-----"},
   {'.', ".-.-.-"},
   {',', "--..--"},
   {'?', "..--.."},
   {'\'', ".---."},
   {'/', "-..-."},
   {'(', "-.--."},
   {')', "-.--.-"},
   {'&', ".-..."},
   {':', "---..."},
   {';', "-.-.-."},
   {'=', "-...-"},
   {'+', ".-.-."},
   {'-', "-....-"},
   {'+', "..--.-"},
   {'"', ".-..-."},
   {'$', "...-..-"},
   {'@', ".--.-."},
};

// TODO international characters

char *morsemessage = NULL;      // Malloc'd
char *tones = NULL;             // Malloc'd

typedef enum
{
   MIC_IDLE,
   MIC_SIP,
   MIC_RECORD,
} mic_mode_t;
mic_mode_t mic_mode = 0;

typedef enum
{
   SPK_IDLE,
   SPK_SIP,
   SPK_TONE,
   SPK_WAV,
} spk_mode_t;
spk_mode_t spk_mode = 0;

sip_state_t sip_mode;

struct
{
   uint8_t die:1;               // Shutting down
   uint8_t sdpresent:1;         // SD present
   uint8_t doformat:1;          // SD format
   uint8_t dodismount:1;        // Dismount SD
   uint8_t micon:1;             // Sounds required
   uint8_t sharedi2s:1;         // I2S shared for Mic and Spk
   uint8_t ha:1;                // Send HA config
   uint8_t usb:1;               // USB connected
   uint8_t overrun:1;           // Record overrun
} b = { 0 };

const char sd_mount[] = "/sd";
char sdrgb = 0;                 // Colour for SD card
const char *cardstatus = NULL;  // Status of SD card
uint64_t sdsize = 0,            // SD card data
   sdfree = 0;
FILE *volatile sdfile = NULL;

i2s_chan_handle_t mic_handle = { 0 };

#define	MICMS		100
#define	MICQUEUE	32
uint8_t micchannels = 0;        // Channels (1 or 2)
uint8_t micbytes = 0;           // Bytes per channel (2, 3, or 4)
uint32_t micsamples = 0;        // Samples per collection
uint32_t micfreq = 0;           // Actual sample rate
uint8_t *micaudio[MICQUEUE] = { 0 };

#define	SPKMS		100
i2s_chan_handle_t spk_handle = { 0 };

uint8_t spkchannels = 0;        // Channels (1 or 2)
uint8_t spkbytes = 0;           // Bytes per channel (2, 3, or 4)
uint32_t spksamples = 0;        // Samples per collection
uint32_t spkfreq = 0;           // Actual sample rate

volatile uint8_t sdin = 0,
   sdout = 0;
volatile uint32_t idle = 0;

static httpd_handle_t webserver = NULL;

const char *
app_callback (int client, const char *prefix, const char *target, const char *suffix, jo_t j)
{
   if (client || !prefix || target || strcmp (prefix, topiccommand) || !suffix)
      return NULL;              // Not for us or not a command from main MQTTS
   if (!strcasecmp (suffix, "morse"))
   {
      if (morsemessage)
         return "Wait";
      if (jo_here (j) != JO_STRING)
         return "JSON string";
      // TODO allow object with custom WPM, and so on
      morsemessage = jo_strdup (j);
      return NULL;
   }
   if (!strcasecmp (suffix, "dtmf") || !strcasecmp (suffix, "tone"))
   {
      if (tones)
         return "Wait";
      if (jo_here (j) != JO_STRING)
         return "JSON string";
      // TODO allow object with custom timings, and so on
      tones = jo_strdup (j);
      return NULL;
   }
   if (!strcasecmp (suffix, "format"))
   {
      b.doformat = 1;
      return NULL;
   }
   if (suffix && ((haenable && (!strcmp (suffix, "connect") || !strcmp (suffix, "status"))) || !strcmp (suffix, "setting")))
   {
      b.ha = 1;
      return NULL;
   }
   if (!strcasecmp (suffix, "record"))
   {
      if (b.sdpresent && !jo_strcmp (j, "ON"))
         b.micon = 1;
      else
         b.micon = 0;
      return NULL;
   }
   return NULL;
}

void
send_ha_config (void)
{
   b.ha = 0;
 ha_config_switch ("record", name: "Record", cmd: "/record", field: "record", delete:(!haenable && !wifirecord));
}

void
revk_state_extra (jo_t j)
{
   if (vbus.set)
      jo_bool (j, "power", b.usb);
   if (sdcmd.set)
      jo_bool (j, "sdcard", b.sdpresent);
   if (micws.set)
      jo_string (j, "record", b.micon ? "ON" : "OFF");
}

void
revk_web_extra (httpd_req_t * req, int page)
{
   if (micws.set)
   {
      revk_web_setting (req, NULL, "micgain");
      revk_web_setting (req, NULL, "micstereo");
      if (!micstereo)
         revk_web_setting (req, NULL, "micright");
   }
   if (sdcmd.set)
   {
      if (micws.set && rgbled.set)
         revk_web_setting (req, NULL, "micbeep");
      revk_web_setting (req, NULL, "sdsynctime");
      revk_web_setting (req, NULL, "sdrectime");
      revk_web_setting (req, NULL, "sdupload");
      revk_web_setting (req, NULL, "sddelete");
      revk_web_setting (req, NULL, "haenable");
      revk_web_setting (req, NULL, "wifilock");
      revk_web_setting (req, NULL, "wifirecord");
   }
   if (vbus.set)
   {
      revk_web_setting (req, NULL, "wifiusb");
      if (autooff)
         revk_web_setting (req, NULL, "autousb");
   }
   revk_web_setting (req, NULL, "autooff");
   if (micws.set || spklrc.set)
   {
      revk_web_setting (req, NULL, "siphost");
      revk_web_setting (req, NULL, "sipuser");
      revk_web_setting (req, NULL, "sippass");
      revk_web_setting (req, NULL, "sipoutgoing");
   }
   if (spklrc.set)
   {
      revk_web_setting (req, NULL, "morsestart");
   }
}

static void
register_uri (const httpd_uri_t * uri_struct)
{
   esp_err_t res = httpd_register_uri_handler (webserver, uri_struct);
   if (res != ESP_OK)
   {
      ESP_LOGE (TAG, "Failed to register %s, error code %d", uri_struct->uri, res);
   }
}

static void
register_post_uri (const char *uri, esp_err_t (*handler) (httpd_req_t * r))
{
   httpd_uri_t uri_struct = {
      .uri = uri,
      .method = HTTP_POST,
      .handler = handler,
   };
   register_uri (&uri_struct);
}

static void
register_get_uri (const char *uri, esp_err_t (*handler) (httpd_req_t * r))
{
   httpd_uri_t uri_struct = {
      .uri = uri,
      .method = HTTP_GET,
      .handler = handler,
   };
   register_uri (&uri_struct);
}

static esp_err_t
web_root (httpd_req_t * req)
{
   idle = 0;
   if (revk_link_down ())
      return revk_web_settings (req);   // Direct to web set up
   revk_web_head (req, "OpenMic");
   revk_web_send (req, "<h1>%s</h1>", *hostname ? hostname : appname);
   const char *er = NULL;
   jo_t j = revk_web_query (req);
   if (j)
   {
      if (jo_find (j, "tone") || jo_find (j, "dtmf") || jo_find (j, "oa"))
      {
         if (tones)
            er = "Wait until finished";
         else
            tones = jo_strdup (j);
      }
      if (jo_find (j, "morse") || jo_find (j, "ud"))
      {
         if (morsemessage)
            er = "Wait until finished";
         else
            morsemessage = jo_strdup (j);
      }
      jo_free (&j);
   }
   if (spklrc.set)
      revk_web_send (req,
                     "<form method=post><table><tr><td>Morse</td><td><input autofocus name=morse size=80></td></tr><tr><td>DTMF</td><td><input name=tone></td></tr></table><input type=submit value=Send></form>");
   if (er)
      revk_web_send (req, "<p>%s</p>", er);
   if (wifilock && b.sdpresent)
      revk_web_send (req, "<hr><p>For security reasons, settings are disabled whilst the SD card is inserted</p>");
   if (b.overrun)
      revk_web_send (req, "<p>Recording overrun - use faster SD card</p>");
   return revk_web_foot (req, 0, 1, NULL);
}

SemaphoreHandle_t sd_mutex = NULL;
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
void
app_main ()
{
   sd_mutex = xSemaphoreCreateBinary ();
   xSemaphoreGive (sd_mutex);
   revk_boot (&app_callback);
   revk_start ();
   if (micws.num == spklrc.num && micclock.num == spkbclk.num)
      b.sharedi2s = 1;
   httpd_config_t config = HTTPD_DEFAULT_CONFIG ();     // When updating the code below, make sure this is enough
   //  Note that we 're also 4 adding revk' s web config handlers
   config.max_uri_handlers = 8;
   if (!httpd_start (&webserver, &config))
   {
      revk_web_settings_add (webserver);
      register_get_uri ("/", web_root);
      register_post_uri ("/", web_root);
   }
   led_strip_handle_t led_status = NULL;
   if (rgbstatus.set)
   {
      led_strip_config_t strip_config = {
         .strip_gpio_num = rgbstatus.num,
         .max_leds = 2,
         .color_component_format = LED_STRIP_COLOR_COMPONENT_FMT_GRB,
         .led_model = LED_MODEL_WS2812, // LED strip model
         .flags.invert_out = rgbstatus.invert,
      };
      led_strip_rmt_config_t rmt_config = {
         .clk_src = RMT_CLK_SRC_DEFAULT,        // different clock source can lead to different power consumption
         .resolution_hz = 10 * 1000 * 1000,     // 10 MHz
      };
      REVK_ERR_CHECK (led_strip_new_rmt_device (&strip_config, &rmt_config, &led_status));
   }
   // Tasks
   if (spklrc.set && spkbclk.set && spkdata.set)
      revk_task ("spk", spk_task, NULL, 8);
   if (micdata.set && micclock.set)
      revk_task ("mic", mic_task, NULL, 8);
   if (sdcmd.set && sddat0.set && sdclk.set)
      revk_task ("sd", sd_task, NULL, 16);
   if (ir.set)
      revk_task ("ir", ir_task, NULL, 4);
   if (*siphost)
      sip_register (siphost, sipuser, sippass, sip_callback, sipdebug ? sip_debug : NULL);
   // Buttons and LEDs
   revk_gpio_input (button);
   revk_gpio_input (charging);  // On, off, or flashing
   revk_gpio_input (vbus);      // USB status
   uint8_t press = 255;
   uint8_t charge = 0;
   uint8_t usb = 1;
   while (!b.die)
   {
      usleep (100000);
      uint32_t up = uptime ();
      if (autooff && !spk_mode && !mic_mode && (!usb || !autousb))
      {                         // Idle
         if (!idle)
            idle = up + autooff;
         else if (idle < up)
            b.die = 1;
      } else
         idle = 0;
      if (b.ha)
         send_ha_config ();
      if (vbus.set)
      {
         usb = revk_gpio_get (vbus);
         if (usb != b.usb)
         {
            b.usb = usb;
            if (wifiusb)
            {
               if (usb)
                  revk_enable_wifi ();
               else
                  revk_disable_wifi ();
            }
         }
      }
      if (revk_shutting_down (NULL) && b.micon)
         b.micon = 0;
      if (charging.set)
         charge = (charge << 1) | revk_gpio_get (charging);
      if (revk_gpio_get (button))
      {                         // Pressed
         if (press < 255)
            press++;
         if (press == 10 && sip_mode == SIP_IC_ALERT)
            sip_hangup ();
         if (press == 30)
            b.die = 1;
      } else if (press)
      {                         // Released
         if (press < 30)
         {
            if (sip_mode == SIP_IC_ALERT)
               sip_answer ();
            else if (sip_mode == SIP_IC || sip_mode == SIP_OG || sip_mode == SIP_OG_ALERT)
               sip_hangup ();
            else if (press >= 10 && *sipoutgoing)
               sip_call (NULL, sipoutgoing, strchr (sipoutgoing, '@') ? NULL : siphost, sipuser, sippass);
            else if (!b.micon && !b.sdpresent)
               ESP_LOGE (TAG, "No card");
            else
               b.micon = 1 - b.micon;
         }
         press = 0;
      }
      if (led_status)
      {
         uint32_t c = revk_blinker ();
         if (mic_mode == MIC_RECORD)
         {                      // recording
            revk_led (led_status, 0, 16, revk_rgb ('B'));
            revk_led (led_status, 1, 16, revk_rgb ('B'));
         } else
         {
            revk_led (led_status, 0, 255, revk_rgb (!usb ? 'C' : charge == 0xFF ? 'Y' : charge ? 'R' : 'G'));
            revk_led (led_status, 1, 255, c);
         }
         REVK_ERR_CHECK (led_strip_refresh (led_status));
      }
   }
   if (*sdupload && b.sdpresent)
   {                            // Upload
      revk_led (led_status, 0, 255, revk_rgb ('B'));
      revk_led (led_status, 1, 255, revk_rgb ('K'));
      REVK_ERR_CHECK (led_strip_refresh (led_status));
      revk_enable_wifi ();
      revk_wait_wifi (10);
      revk_led (led_status, 1, 255, revk_rgb ('R'));
      REVK_ERR_CHECK (led_strip_refresh (led_status));
      do_upload ();
   }
   // Go dark
   if (led_status)
   {
      revk_led (led_status, 0, 255, 0);
      revk_led (led_status, 1, 255, 0);
      REVK_ERR_CHECK (led_strip_refresh (led_status));
   }
   revk_pre_shutdown ();
   // Alarm
   if (rtc_gpio_is_valid_gpio (button.num))
   {                            // Deep sleep
      rtc_gpio_set_direction_in_sleep (button.num, RTC_GPIO_MODE_INPUT_ONLY);
      rtc_gpio_pullup_en (button.num);
      rtc_gpio_pulldown_dis (button.num);
      REVK_ERR_CHECK (esp_sleep_enable_ext0_wakeup (button.num, 1 - button.invert));
   } else
   {                            // Light sleep
      gpio_wakeup_enable (button.num, GPIO_INTR_LOW_LEVEL);
      esp_sleep_enable_gpio_wakeup ();
   }
   // Shutdown
   sleep (1);                   // Allow tasks to end
   // Night night
   if (rtc_gpio_is_valid_gpio (button.num))
      esp_deep_sleep_start ();
   else
      esp_light_sleep_start ();
   esp_restart ();
}

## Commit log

2024-11-09 Rework concept
    [Audio.kicad_pcb, Audio.kicad_sch]
2024-11-09 Initial tracking
    [Audio.kicad_pcb, Audio.kicad_sch, bom.csv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]
2024-11-09 Tidy tracks
    [Audio.kicad_pcb]
2024-11-10 Not LED
2024-11-10 Slot fix
    [Audio.kicad_pcb]
2024-11-11 Cap clash moved
    [Audio.kicad_pcb, positions.csv]
2024-11-16 DNP J1 as clashes
    [Audio.kicad_pcb, Audio.kicad_sch]
2024-11-23 SD mount
2024-11-23 Rework, and pull ups
    [Audio.kicad_pcb, Audio.kicad_sch, bom.csv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]
2024-11-24 Charging LED
2024-11-25 Work on samples and SIP mode
2024-11-25 Started on OSC board
    [OCS.kicad_pcb, OCS.kicad_sch]
2024-11-25 Getting basic BOM
    [OCS.kicad_pcb, OCS.kicad_sch]
2024-11-25 No charger?
2024-11-27 New layout
    [Audio.kicad_pcb, Audio.kicad_sch, OCS.kicad_pcb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]
2024-11-27 Correct SS
    [Audio.kicad_pcb]
2024-11-27 Ready to order
    [OCS.kicad_pcb, OCS.kicad_sch, bom.csv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]
2024-11-28 Moved LEDs
    [Audio.kicad_pcb, CommBadge.kicad_pcb, CommBadge.kicad_sch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]
2024-11-29 Reworked to have speaker, and VBUS test.
    [Audio.kicad_pcb, Audio.kicad_sch, bom.csv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]
2024-12-01 Start on intercom
    [Intercom.kicad_pcb, Intercom.kicad_sch]
2024-12-01 Fix oldest file logic
    [Audio.c]
2024-12-01 Upload and delete logic fix
    [Audio.c]
2024-12-01 Tidy SS
    [Intercom.kicad_pcb, Intercom.kicad_sch, Recorder.kicad_pcb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]
2024-12-02 STart logci
    [CommBadge.kicad_pcb, CommBadge.kicad_sch]
2024-12-02 Green LED
2024-12-02 lower power when recording
2024-12-02 HA record button
2024-12-03 Fix component size
    [Recorder.kicad_pcb, Recorder.kicad_sch, bom.csv]
2024-12-03 Button stuff
2024-12-03 Fix footprints
    [Recorder.kicad_pcb]
2024-12-06 Morse 600Hz is more standard
2024-12-10 Started IR but not working on test board
    [OpenMic.c]
2024-12-12 Mdae longer
    [Recorder.kicad_pcb]
2024-12-12 LED tidy
2024-12-16 File sync and truncation issues fixed
    [OpenMic.c]
2024-12-16 Allow all data on SD card maybe
    [Recorder.kicad_pcb, Recorder.kicad_sch, positions.csv]
2024-12-17 Working on alt to SPI SD mode
2024-12-17 MMC mode (faster than SPI)
2024-12-17 Clean up
    [Recorder.kicad_pcb, positions.csv]
2024-12-17 New mic artwork
    [CommBadge.kicad_pcb]
2024-12-18 Charging is 11 not 18 FFS
    [Recorder.kicad_pcb, Recorder.kicad_sch, bom.csv]
2024-12-18 No SPI mode
2024-12-18 New LED logic
2024-12-18 New LED
2024-12-20 Snap off
    [Recorder.kicad_pcb]
2024-12-20 More SS
    [Recorder.kicad_pcb]
